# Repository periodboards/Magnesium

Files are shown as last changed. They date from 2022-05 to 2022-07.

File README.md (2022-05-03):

# Magnesium
My crappy 14-key macropad that contains many mistakes in the design

## Errors
### RGB backlighting doesn't work
Somehow in the many days that I had worked on routing the backlighting, I never noticed that I used the wrong LED footprint and so the leds are on the wrong side of the board

### The WS2812 was wired incorrectly
The power and ground were swapped on the WS2812, and therefore if you want to have underglow you need to use a bodge wire to connect data in to what was data out and rotate all of the LEDs accordingly

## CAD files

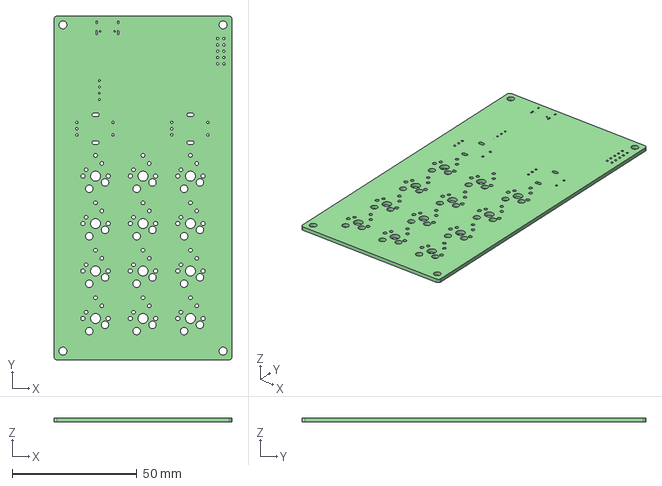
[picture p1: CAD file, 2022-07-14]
MgBoard.step
71.4 x 138.1 x 1.60 mm

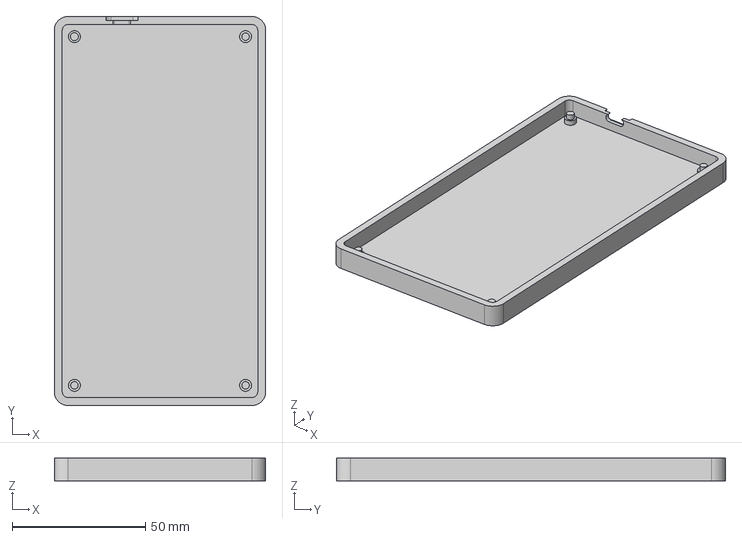
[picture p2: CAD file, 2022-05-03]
Models/MagnesiumCase.step
79.4 x 146.1 x 8.60 mm

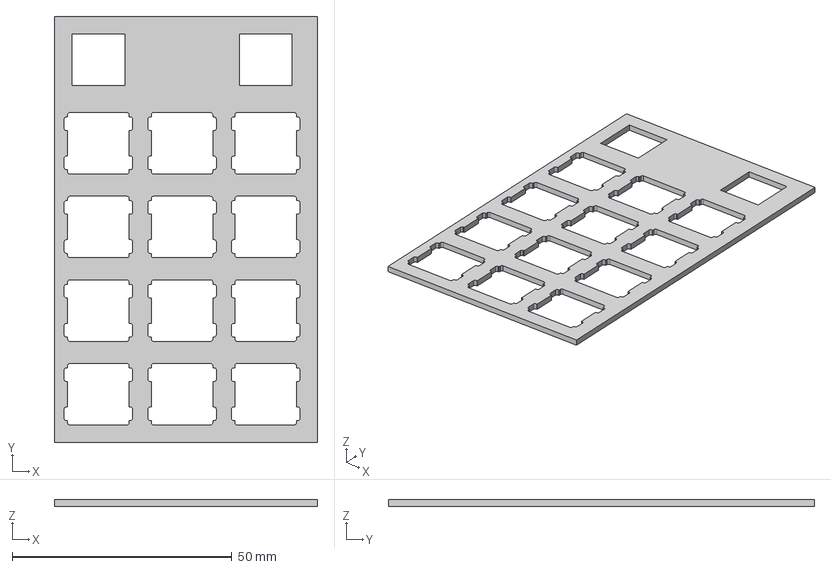
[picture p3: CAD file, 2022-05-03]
Models/MagnesiumPlate.step
59.9 x 97.0 x 1.50 mm

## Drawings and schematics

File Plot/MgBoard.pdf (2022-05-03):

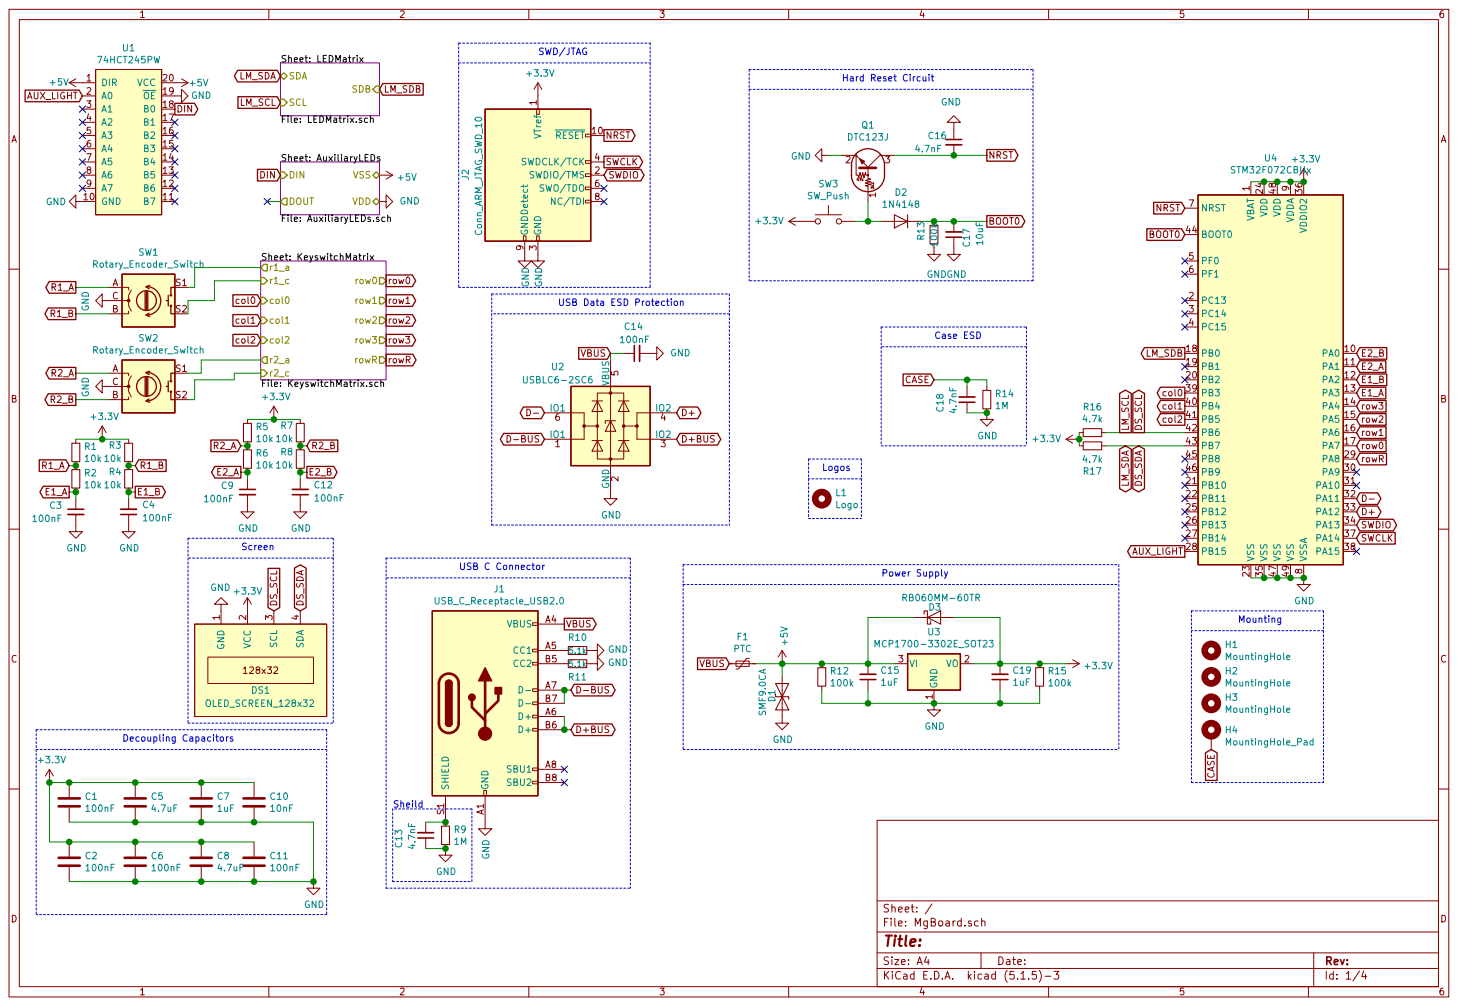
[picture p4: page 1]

Hard Reset Circuit SWD/JTAG

9 U4 STM32F072CBUx +5V GNDGND VTref 1 RESET 10 SWDIO/TMS 2 GND

3 SWDCLK/TCK 4 SWO/TDO 6 NC/TDI 8 GNDDetect 9 J2 Conn_ARM_JTAG_SWD_10 R10

Sheet: AuxiliaryLEDs
File: AuxiliaryLEDs.sch VSS

1 PA0 10 PA1 11 PA2 12 PA3 13 PA4 14 PA5 15 PA6 16 PA7 17 PB0 18 PB1 19 PC13 2 PB2 20 PB10 21 PB11 22 VSS 23 VDD 24 PB12 25 PB13 26 PB14 27 PB15 28 PA8 29 PC14 3 PA9 30 PA10 31 PA11 32 PA12 33 PA13 34 VSS 35 VDDIO2 36 PA14 37 PA15 38 PB3 39 PC15 4 PB4 40 PB5 41 PB6 42 PB7 43 BOOT0 44 PB8 45 PB9 46 VSS 47 VDD 48 VSS 49 PF0 5 PF1 6 NRST 7 VSSA

File: MgBoard.sch Sheet: /
Id: 1/4 Title:

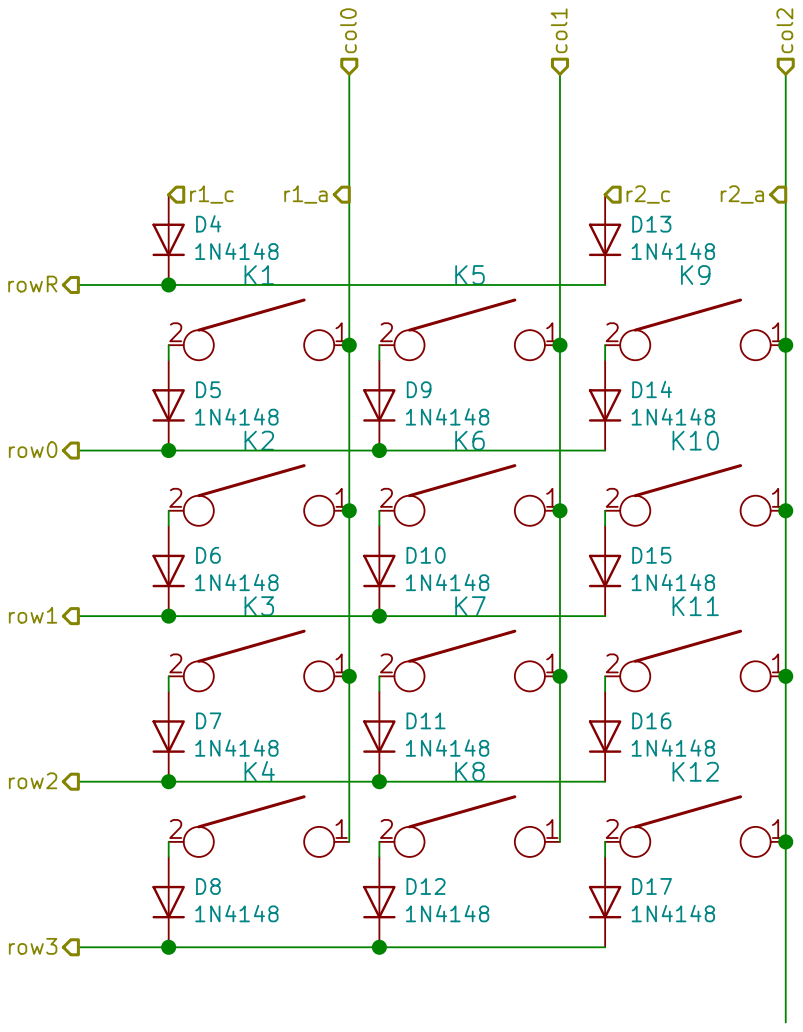
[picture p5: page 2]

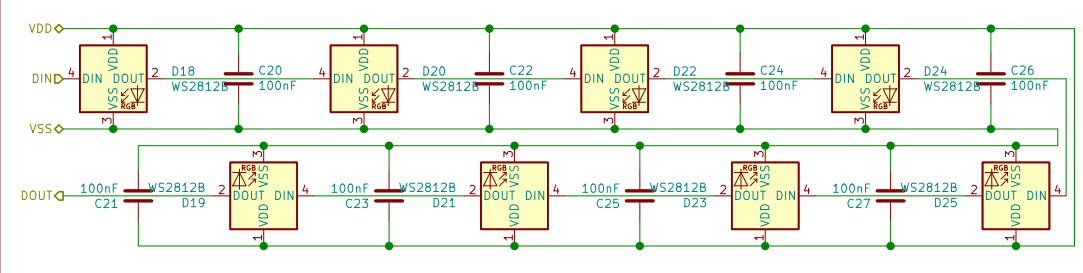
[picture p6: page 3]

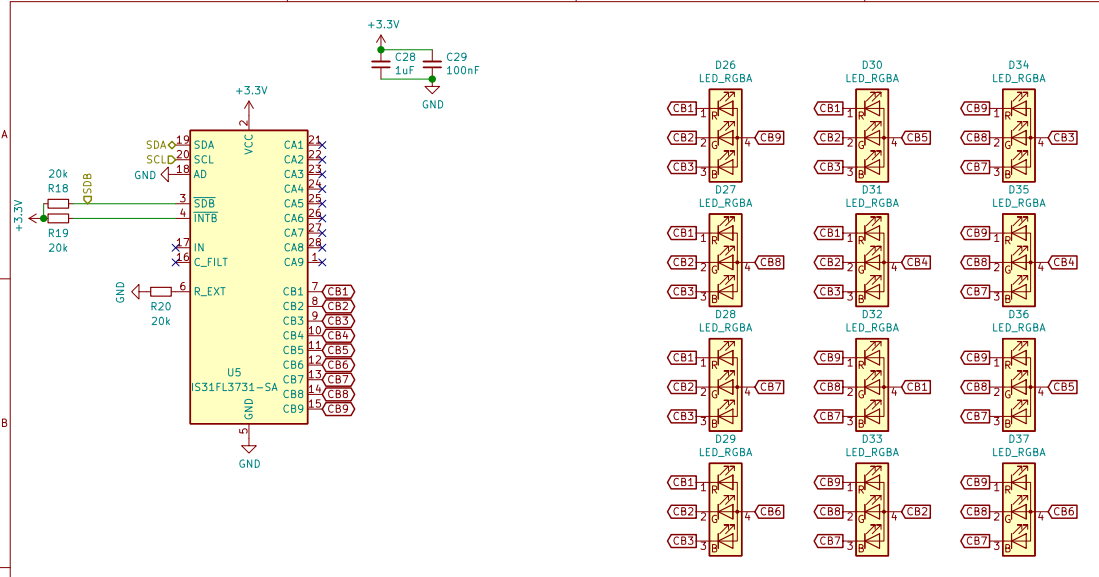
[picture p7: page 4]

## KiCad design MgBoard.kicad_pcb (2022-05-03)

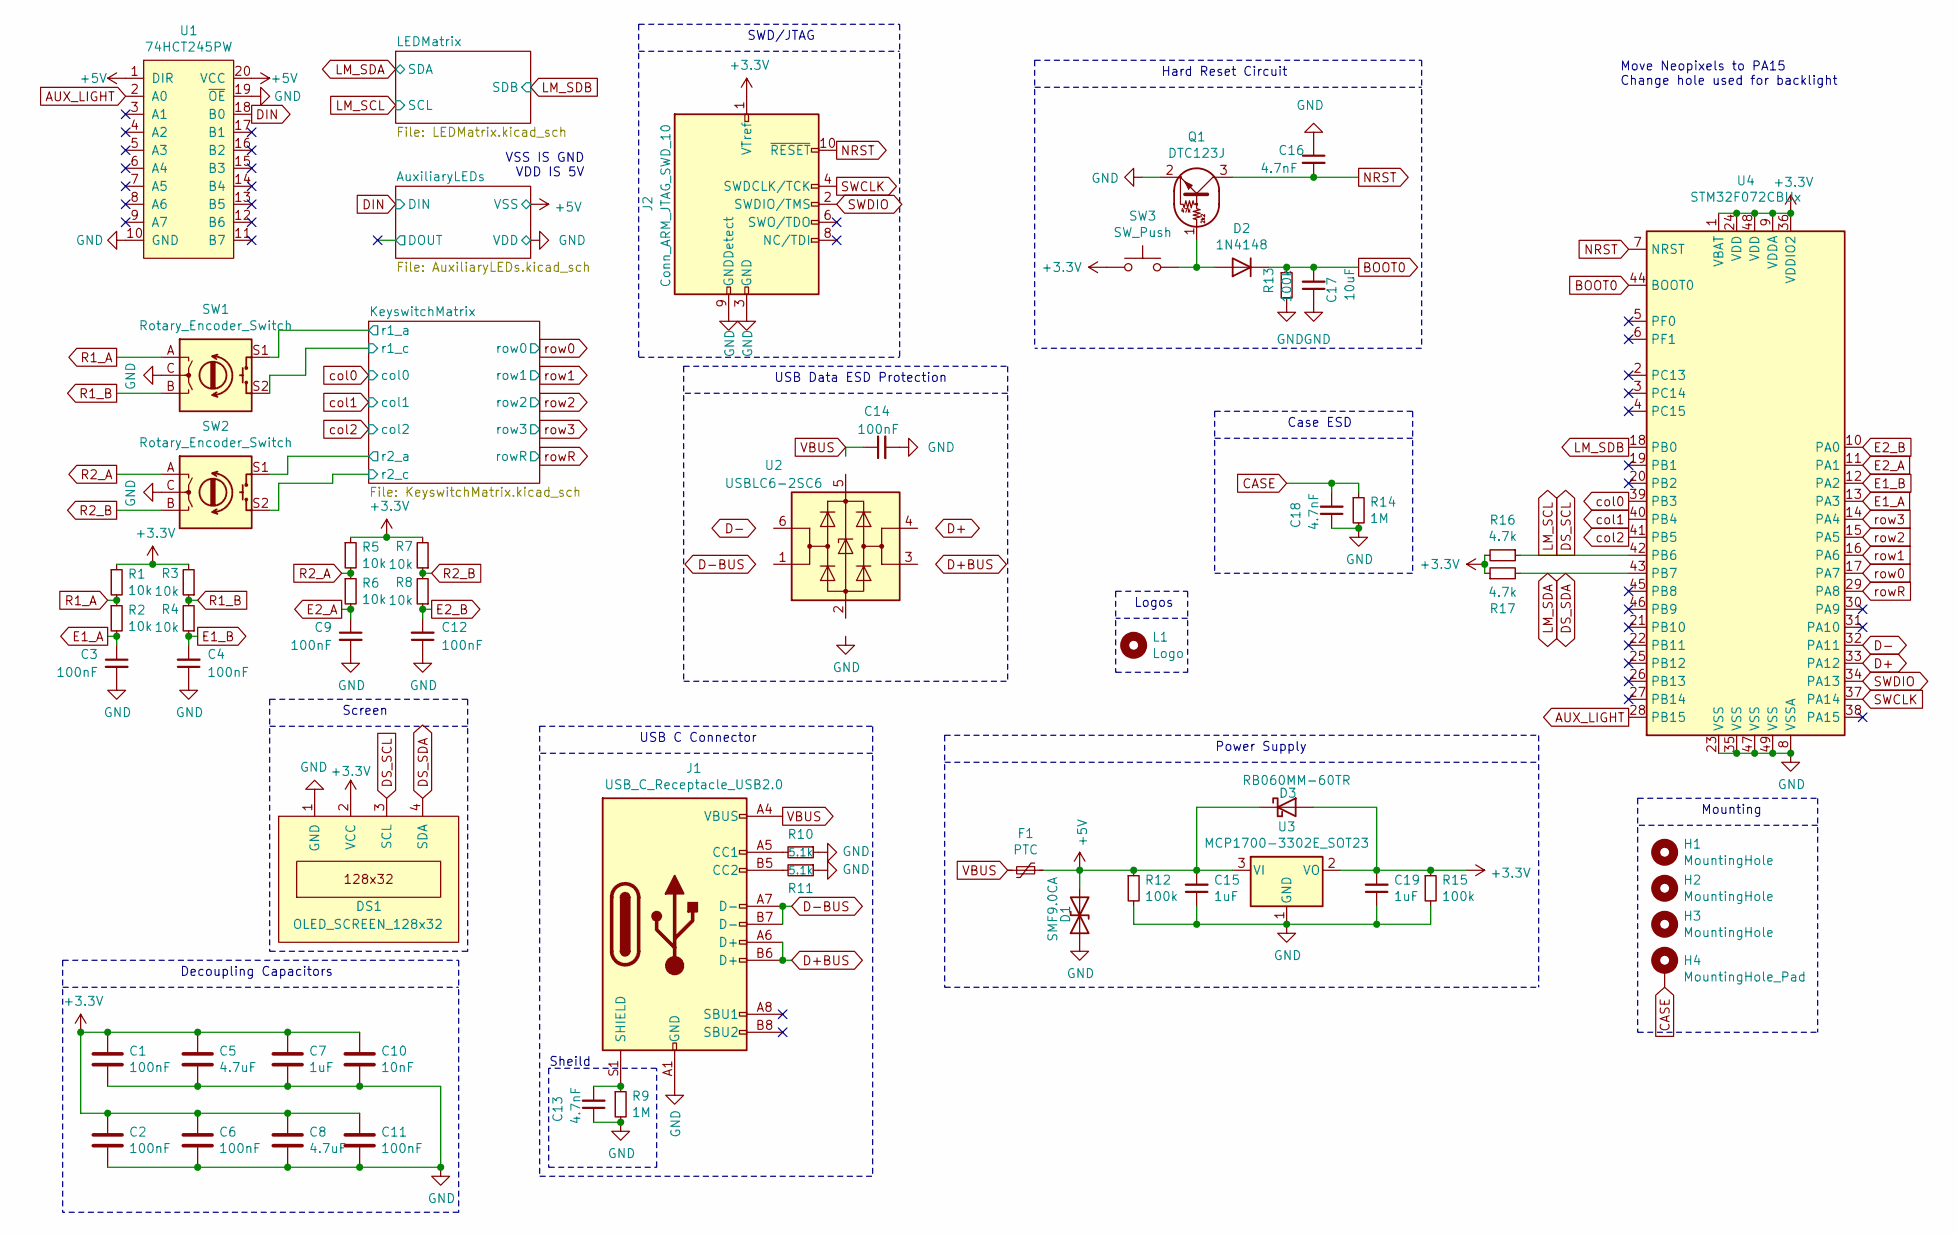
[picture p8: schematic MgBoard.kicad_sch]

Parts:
C1, C2, C3, C4, C6, C9, C11, C12, C14: 100nF; C_0603_1608Metric_Pad1.05x0.95mm_HandSolder
C5, C8: 4.7uF; C_0603_1608Metric_Pad1.05x0.95mm_HandSolder
C7, C15, C19: 1uF; C_0603_1608Metric_Pad1.05x0.95mm_HandSolder
C10: 10nF; C_0603_1608Metric_Pad1.05x0.95mm_HandSolder
C13, C16, C18: 4.7nF; C_0603_1608Metric_Pad1.05x0.95mm_HandSolder
C17: 10uF; C_0603_1608Metric_Pad1.05x0.95mm_HandSolder
D1: SMF9.0CA; D_SOD-123F
D2: 1N4148; D_SOD-123
D3: RB060MM-60TR; D_SOD-123F
DS1: OLED_SCREEN_128x32
F1: PTC; Fuse_1206_3216Metric_Pad1.42x1.75mm_HandSolder
H1, H2, H3: MountingHole; MountingHole_3.2mm_M3_ISO14580
H4: MountingHole_Pad; MountingHole_3.2mm_M3_ISO14580_Pad
J1: USB_C_Receptacle_USB2.0; USB_C_Receptacle_HRO_TYPE-C-31-M-12
J2: Conn_ARM_JTAG_SWD_10; PinHeader_2x05_P2.54mm_Vertical
L1: Logo; Mg
Q1: DTC123J; SOT-323_SC-70_Handsoldering
R1, R2, R3, R4, R5, R6, R7, R8: 10k; R_0603_1608Metric_Pad1.05x0.95mm_HandSolder
R9, R14: 1M; R_0603_1608Metric_Pad1.05x0.95mm_HandSolder
R10, R11: 5.1k; R_0603_1608Metric_Pad1.05x0.95mm_HandSolder
R12, R13, R15: 100k; R_0603_1608Metric_Pad1.05x0.95mm_HandSolder
R16, R17: 4.7k; R_0603_1608Metric_Pad1.05x0.95mm_HandSolder
SW1, SW2: Rotary_Encoder_Switch; RotaryEncoder_Alps_EC11E-Switch_Vertical_H20mm_1u
SW3: SW_Push; SW_SPST_SKQG_WithStem
U1: 74HCT245PW; TSSOP-20_4.4x6.5mm_P0.65mm
U2: USBLC6-2SC6; SOT-23-6_Handsoldering
U3: MCP1700-3302E_SOT23; SOT-23_Handsoldering
U4: STM32F072CBUx; QFN-48-1EP_7x7mm_P0.5mm_EP5.6x5.6mm

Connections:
+3V3: C1.1, C2.1, C5.1, C6.1, C7.1, C8.1, C10.1, C11.1, C19.2, D3.2 (A), DS1.2 (VCC), J2.1 (VTref), R1.1, R3.2, R5.1, R7.2, R15.1, R16.2, R17.1, SW3.1, U3.2 (VO), U4.1 (VBAT), U4.9 (VDDA), U4.24 (VDD), U4.36 (VDDIO2), U4.48 (VDD); also elsewhere on the board
+5V: C15.2, D1.2 (A2), D3.1 (K), F1.1, R12.1, U1.1 (DIR), U1.20 (VCC), U3.3 (VI); also elsewhere on the board
/KeyswitchMatrix/r1_c: SW1.S2; also elsewhere on the board
/KeyswitchMatrix/r2_c: SW2.S2; also elsewhere on the board
AUX_LIGHT: U1.2 (A0), U4.28 (PB15)
BOOT0: C17.2, D2.1 (K), R13.1, U4.44 (BOOT0)
CASE: C18.2, H4.1, R14.1
D+: U2.4 (I/O2), U4.33 (PA12)
D+BUS: J1.A6 (D+), J1.B6 (D+), U2.3 (I/O2)
D-: U2.6 (I/O1), U4.32 (PA11)
D-BUS: J1.A7 (D-), J1.B7 (D-), U2.1 (I/O1)
DIN: U1.18 (B0); also elsewhere on the board
DS_SCL: DS1.3 (SCL), R16.1, U4.42 (PB6); also elsewhere on the board
DS_SDA: DS1.4 (SDA), R17.2, U4.43 (PB7); also elsewhere on the board
E1_A: C3.1, R2.2, U4.13 (PA3)
E1_B: C4.2, R4.1, U4.12 (PA2)
E2_A: C9.1, R6.2, U4.11 (PA1)
E2_B: C12.2, R8.1, U4.10 (PA0)
GND: C1.2, C2.2, C3.2, C4.1, C5.2, C6.2, C7.2, C8.2, C9.2, C10.2, C11.2, C12.1, C13.1, C14.2, C15.1, C16.1, C17.1, C18.1, C19.1, D1.1 (A1), DS1.1 (GND), J1.A1 (GND), J1.A12 (GND), J1.B1 (GND), J1.B12 (GND), J2.3 (GND), J2.5 (GND), J2.9 (GNDDetect), Q1.2 (E), R9.2, R10.1, R11.1, R12.2, R13.2, R14.2, R15.2, SW1.C, SW2.C, U1.10 (GND), U1.19 (~OE), U2.2 (GND), U3.1 (GND), U4.8 (VSSA), U4.23 (VSS), U4.35 (VSS), U4.47 (VSS), U4.49 (VSS); also elsewhere on the board
LM_SDB: U4.18 (PB0); also elsewhere on the board
NRST: C16.2, J2.10 (~RESET~), Q1.3 (C), U4.7 (NRST)
unnamed: C13.2, J1.S1 (SHIELD), R9.1
unnamed: D2.2 (A), Q1.1 (B), SW3.2
unnamed: J1.A5 (CC1), R10.2
unnamed: J1.B5 (CC2), R11.2
R1_A: R1.2, R2.1, SW1.A
R1_B: R3.1, R4.2, SW1.B
R2_A: R5.2, R6.1, SW2.A
R2_B: R7.1, R8.2, SW2.B
SWCLK: J2.4 (SWDCLK/TCK), U4.37 (PA14)
SWDIO: J2.2 (SWDIO/TMS), U4.34 (PA13)
VBUS: C14.1, F1.2, J1.A4 (VBUS), J1.A9 (VBUS), J1.B4 (VBUS), J1.B9 (VBUS), U2.5 (VBUS)
col0: SW1.S1, U4.39 (PB3); also elsewhere on the board
col1: U4.40 (PB4); also elsewhere on the board
col2: SW2.S1, U4.41 (PB5); also elsewhere on the board
row0: U4.17 (PA7); also elsewhere on the board
row1: U4.16 (PA6); also elsewhere on the board
row2: U4.15 (PA5); also elsewhere on the board
row3: U4.14 (PA4); also elsewhere on the board
rowR: U4.29 (PA8); also elsewhere on the board

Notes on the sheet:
Decoupling Capacitors
Screen
Sheild
VSS IS GND VDD IS 5V
USB C Connector
SWD/JTAG
USB Data ESD Protection
Logos
Hard Reset Circuit
Power Supply
Case ESD
Move Neopixels to PA15 Change hole used for backlight
Mounting

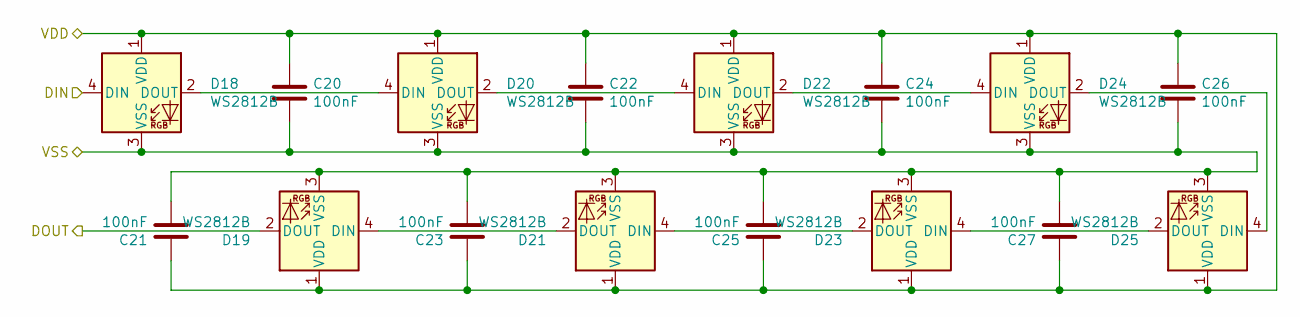
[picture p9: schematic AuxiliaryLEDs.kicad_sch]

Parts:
C20, C21, C22, C23, C24, C25, C26, C27: 100nF; C_0603_1608Metric_Pad1.05x0.95mm_HandSolder
D18, D19, D20, D21, D22, D23, D24, D25: WS2812B; LED_WS2812B_PLCC4_5.0x5.0mm_P3.2mm

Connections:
+5V: C20.1, C21.1, C22.1, C23.1, C24.1, C25.1, C26.1, C27.1, D18.3 (VSS), D19.3 (VSS), D20.3 (VSS), D21.3 (VSS), D22.3 (VSS), D23.3 (VSS), D24.3 (VSS), D25.3 (VSS); also elsewhere on the board
/AuxiliaryLEDs/DOUT: D19.2 (DOUT)
DIN: D18.4 (DIN); also elsewhere on the board
GND: C20.2, C21.2, C22.2, C23.2, C24.2, C25.2, C26.2, C27.2, D18.1 (VDD), D19.1 (VDD), D20.1 (VDD), D21.1 (VDD), D22.1 (VDD), D23.1 (VDD), D24.1 (VDD), D25.1 (VDD); also elsewhere on the board
unnamed: D18.2 (DOUT), D20.4 (DIN)
unnamed: D19.4 (DIN), D21.2 (DOUT)
unnamed: D20.2 (DOUT), D22.4 (DIN)
unnamed: D21.4 (DIN), D23.2 (DOUT)
unnamed: D22.2 (DOUT), D24.4 (DIN)
unnamed: D23.4 (DIN), D25.2 (DOUT)
unnamed: D24.2 (DOUT), D25.4 (DIN)

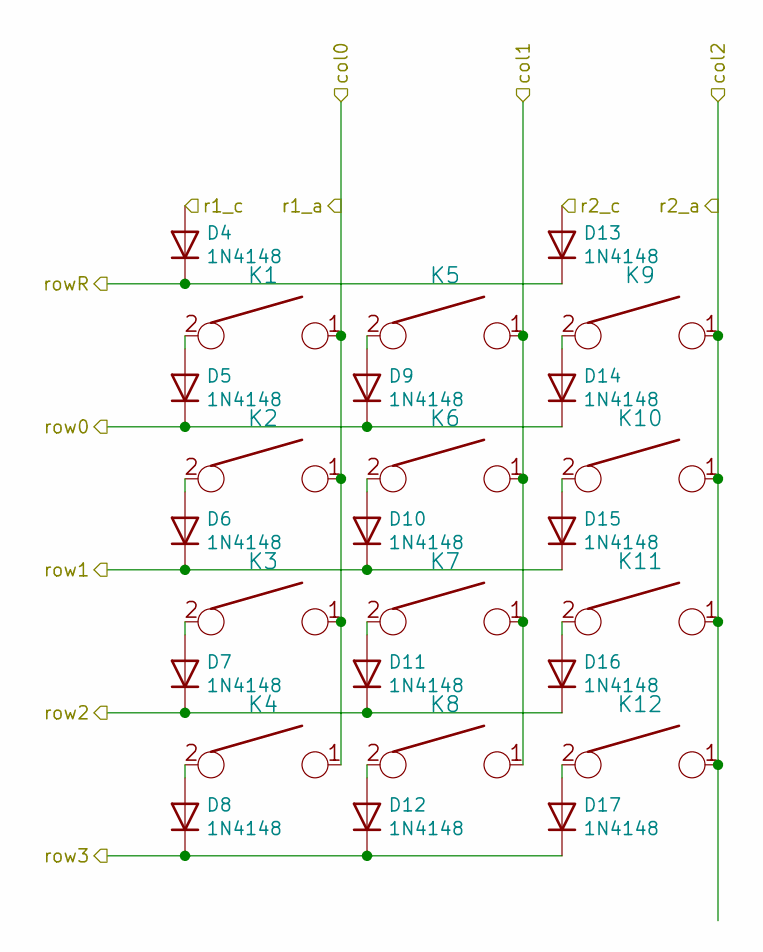
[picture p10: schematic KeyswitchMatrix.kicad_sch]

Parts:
D4, D5, D6, D7, D8, D9, D10, D11, D12, D13, D14, D15, D16, D17: 1N4148; D_SOD-123
K1, K2, K3, K4, K5, K6, K7, K8, K9, K10, K11, K12: KEYSW; Kailh_socket_MX_optional_1u

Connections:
/KeyswitchMatrix/r1_c: D4.2 (A); also elsewhere on the board
/KeyswitchMatrix/r2_c: D13.2 (A); also elsewhere on the board
unnamed: D5.2 (A), K1.2
unnamed: D6.2 (A), K2.2
unnamed: D7.2 (A), K3.2
unnamed: D8.2 (A), K4.2
unnamed: D9.2 (A), K5.2
unnamed: D10.2 (A), K6.2
unnamed: D11.2 (A), K7.2
unnamed: D12.2 (A), K8.2
unnamed: D14.2 (A), K9.2
unnamed: D15.2 (A), K10.2
unnamed: D16.2 (A), K11.2
unnamed: D17.2 (A), K12.2
col0: K1.1, K2.1, K3.1, K4.1; also elsewhere on the board
col1: K5.1, K6.1, K7.1, K8.1; also elsewhere on the board
col2: K9.1, K10.1, K11.1, K12.1; also elsewhere on the board
row0: D5.1 (K), D9.1 (K), D14.1 (K); also elsewhere on the board
row1: D6.1 (K), D10.1 (K), D15.1 (K); also elsewhere on the board
row2: D7.1 (K), D11.1 (K), D16.1 (K); also elsewhere on the board
row3: D8.1 (K), D12.1 (K), D17.1 (K); also elsewhere on the board
rowR: D4.1 (K), D13.1 (K); also elsewhere on the board

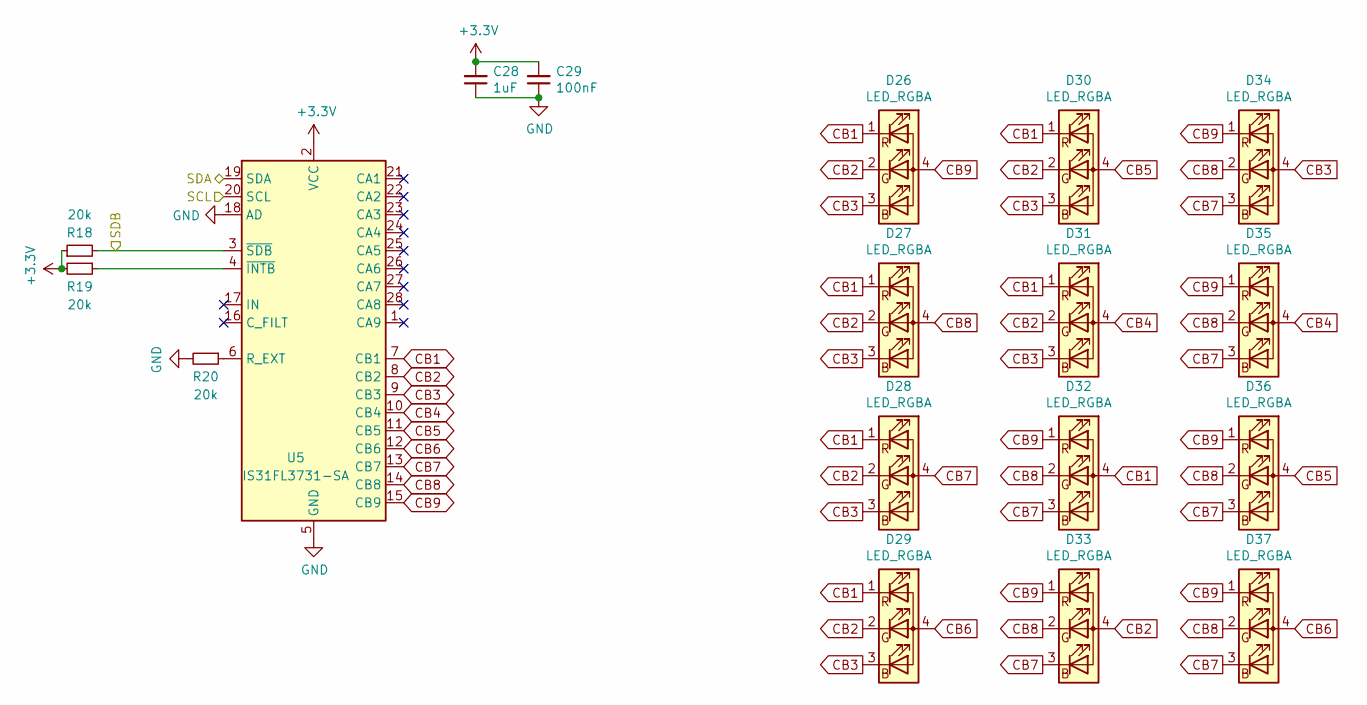
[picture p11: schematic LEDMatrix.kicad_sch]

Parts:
C28: 1uF; C_0603_1608Metric_Pad1.05x0.95mm_HandSolder
C29: 100nF; C_0603_1608Metric_Pad1.05x0.95mm_HandSolder
D26, D27, D28, D29, D30, D31, D32, D33, D34, D35, D36, D37: LED_RGBA; LED_RGBA_Reverse
R18, R19, R20: 20k; R_0603_1608Metric_Pad1.05x0.95mm_HandSolder
U5: IS31FL3731-SA; SSOP-28_5.3x10.2mm_P0.65mm

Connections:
+3V3: C28.2, C29.2, R18.1, R19.2, U5.2 (VCC); also elsewhere on the board
CB1: D26.1 (RK), D27.1 (RK), D28.1 (RK), D29.1 (RK), D30.1 (RK), D31.1 (RK), D32.4 (A), U5.7 (CB1)
CB2: D26.2 (GK), D27.2 (GK), D28.2 (GK), D29.2 (GK), D30.2 (GK), D31.2 (GK), D33.4 (A), U5.8 (CB2)
CB3: D26.3 (BK), D27.3 (BK), D28.3 (BK), D29.3 (BK), D30.3 (BK), D31.3 (BK), D34.4 (A), U5.9 (CB3)
CB4: D31.4 (A), D35.4 (A), U5.10 (CB4)
CB5: D30.4 (A), D36.4 (A), U5.11 (CB5)
CB6: D29.4 (A), D37.4 (A), U5.12 (CB6)
CB7: D28.4 (A), D32.3 (BK), D33.3 (BK), D34.3 (BK), D35.3 (BK), D36.3 (BK), D37.3 (BK), U5.13 (CB7)
CB8: D27.4 (A), D32.2 (GK), D33.2 (GK), D34.2 (GK), D35.2 (GK), D36.2 (GK), D37.2 (GK), U5.14 (CB8)
CB9: D26.4 (A), D32.1 (RK), D33.1 (RK), D34.1 (RK), D35.1 (RK), D36.1 (RK), D37.1 (RK), U5.15 (CB9)
DS_SCL: U5.20 (SCL); also elsewhere on the board
DS_SDA: U5.19 (SDA); also elsewhere on the board
GND: C28.1, C29.1, R20.2, U5.5 (GND), U5.18 (AD); also elsewhere on the board
LM_SDB: R18.2, U5.3 (~SDB); also elsewhere on the board
unnamed: R19.1, U5.4 (~INTB)
unnamed: R20.1, U5.6 (R_EXT)

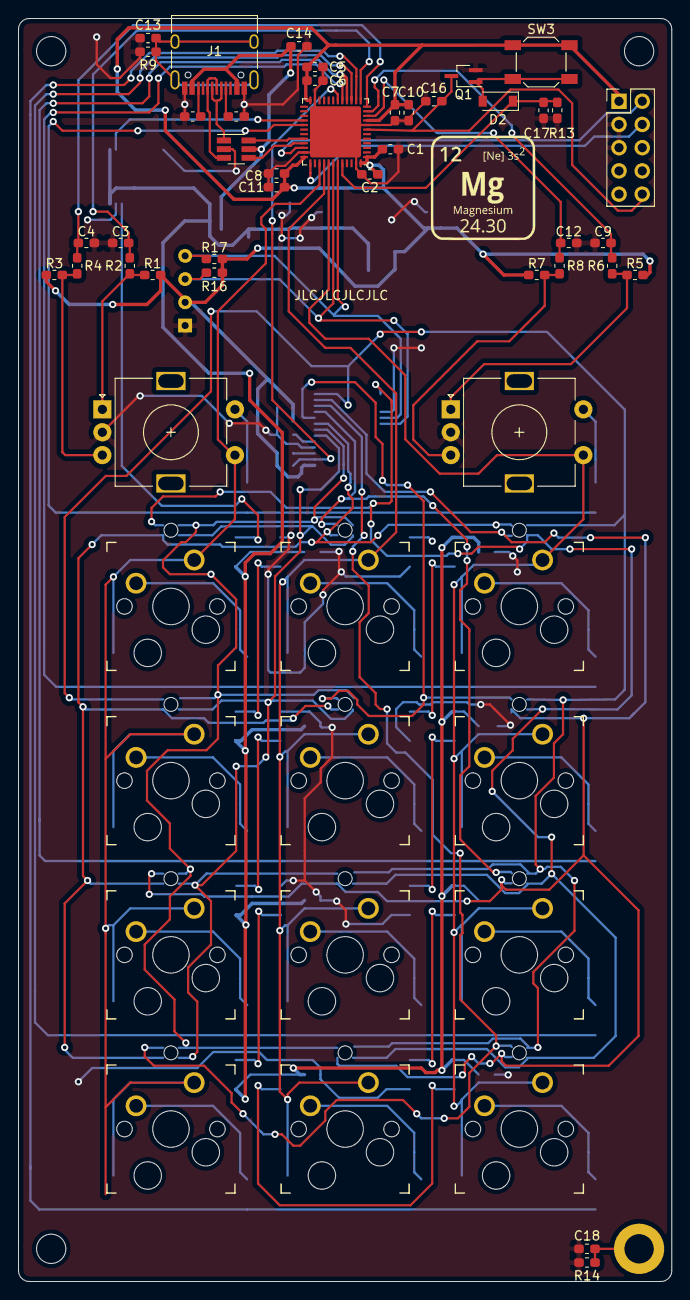
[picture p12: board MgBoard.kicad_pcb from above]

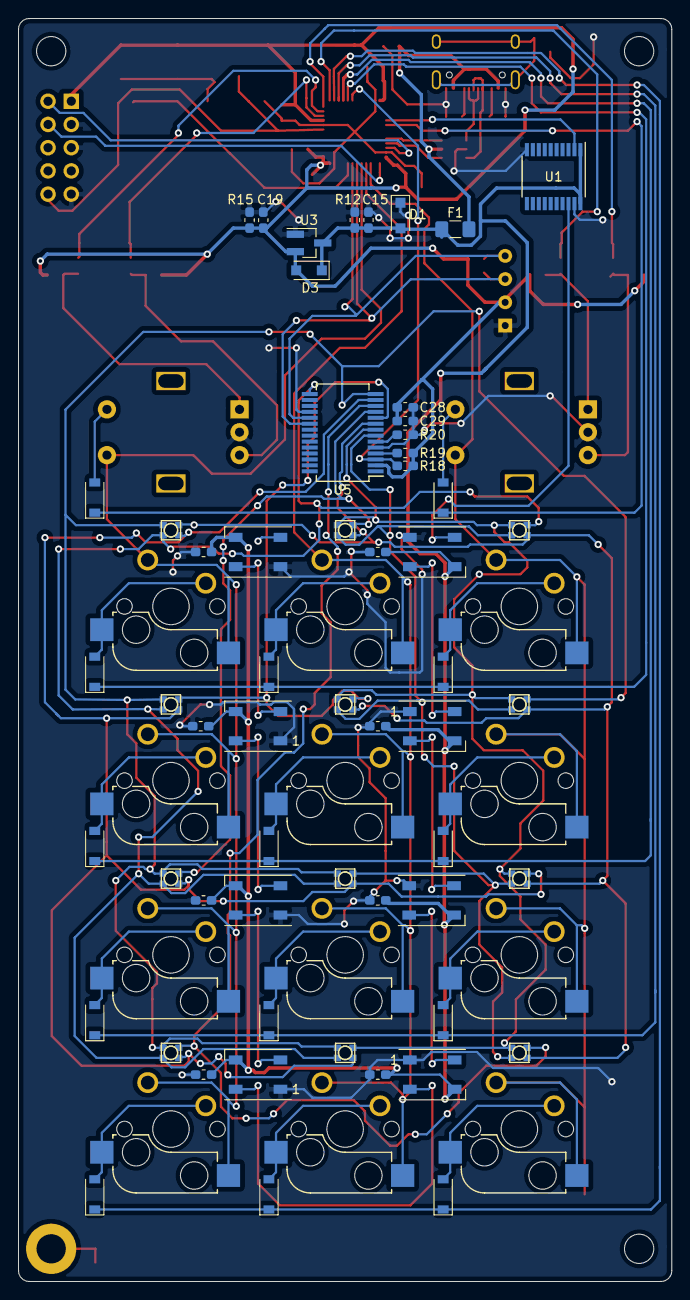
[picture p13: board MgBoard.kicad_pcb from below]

Board: 2 copper layers, 71.4 x 138.1 mm, 116 parts (45 on the bottom side), 70 nets.

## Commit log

2022-05-03 All of the crud
    [AuxiliaryLEDs.kicad_sch, AuxiliaryLEDs.sch, KeyswitchMatrix.kicad_sch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]
2022-05-03 Added 3d model of case and plate
    [MagnesiumCase.step, MagnesiumPlate.step]
